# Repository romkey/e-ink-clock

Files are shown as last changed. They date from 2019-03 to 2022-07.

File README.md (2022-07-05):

# e-ink wifi clock



_This is a work in progress. I'm still testing and updating the hardware, and the software is incomplete. Build at your own risk._

Use a Waveshare epaper (e-ink) display as a digital wifi clock. The clock synchronizes its time with NTP and can show local weather using OpenWeatherMap.

The clock also supports an optional environmental sensor module, which allows it to report the temperature, humidity and air pressure in the space it's in.

It also supports an optional DS3231 I2C real time clock with battery backup module. This allows it to know the time immediately upon booting, even without NTP, and to keep time more accurately than just the ESP32 is capable of.

FInally, it also supports an optional ambient light sensor. This allows the clock to power down the e-ink module in the dark (when it is unreadable), which should extend the lifespan of the module.

# Hardware

Eagle schematics and board are in the `eagle` directory. 

_The hardware is still in testing; I cannot make any promises about its suitability for any use or its reliability._

Prices are obviously from the time I made this list. Links to parts are meant to show parts that have identical pinouts to the ones I used in the PC board layout. The specific items may become unavailable over time or the listings might even change to other parts with incompatible pinouts, so *please be careful to make sure you get parts with the correct pinouts* if you want to use the PC board - this is meant to be a guide to the parts and not a specific shopping list. 

| Part | AliExpress | Amazon | Notes |
|---|---:|---:|--|
|Waveshare 4.2" epaper module | [$28.79](https://www.aliexpress.com/item/400x300-4-2inch-E-Ink-display-module-No-backlight-Ultra-low-power-consumption-SPI-interface-Compatible/32826601765.html) | [$38.99](https://www.amazon.com/gp/product/B074NR1SW2) | |
|Wemos LOLIN32 ESP32 | [$5.50](https://www.aliexpress.com/item/ESP-32-ESP32-ESP-WROOM-32-for-WeMos-D1-LOLIN32-V1-0-02-WIFI-Bluetooth-Development/32887251214.html) | [$9.99 + $4.99](https://www.amazon.com/Beaster-LOLIN32-V1-0-0-Bluetooth-Development/dp/B07KFF1GJK) | |
|BME280 breakout | [$2.50](https://www.aliexpress.com/item/High-Accuracy-3In1-BME280-Digital-Sensor-Temperature-Humidity-Barometric-Pressure-Sensor-Module-GY-BME280-I2C-SPI/32817230797.html) | [$11.20](https://www.amazon.com/gp/product/B0775XFW69) | *optional*  lets you read the temperature, hunmidity and pressure where the clock is |
|DS3231 RTC breakout | [$1.04](https://www.aliexpress.com/item/DS3231-AT24C32-IIC-High-Precision-RTC-Module-Clock-Timer-Memory-Module/2037934408.html) | [$6.99](https://www.amazon.com/gp/product/B01IXXACD0) | *optional* keeps more accurate time, works without NTP or wifi |
|photoresistor | []() | []() | *optional* lets the clock power off display in the dark |
| |$37.83 | $72.16 |

Obviously AliExpress is an economical choice if you can wait a month or more for your parts to arrive. 

The printed circuit board uses breakout boards and is easy to assemble. The current version is at https://oshpark.com/shared_projects/apAIFWjg

# Software

The e-ink clock software is built using the Arduino SDK. It builds under [PlatformIO](https://platformio.org/) but with a little rearranging you could also build it with the Arduino IDE.

The application uses the [GxEPD](https://github.com/ZinggJM/GxEPD) library to drive the Waveshare display. GxEPD is a subclass of [Adafruit_GFX](https://github.com/adafruit/Adafruit-GFX-Library), so you can use its API to talk to the display. It also supports fast partial update on some Waveshare displays, which lets you write to the display much faster than a full screen write, without distracting flashing.

## Resources:

- turn an image file into a C language bitmap - [image2cpp](https://javl.github.io/image2cpp/)
- use `fontconvert` from Adafruit GFX Library to convert fonts to Adafruit GFX format

## Configuration

Copy `src/config.h-example` to `src/config.h` and set the constants in the file as you need them:
- `WIFI_SSID1`, `WIFI_PASSWORD1` - your primary WiFi SSID and password 
- `WIFI_SSID2`, `WIFI_PASSWORD2` - your backup WiFi SSID and password  - set to the same as primary if you don't have a backup
- `WIFI_SSID3`, `WIFI_PASSWORD3` - your bakup backup WiFi SSID and password  - set to the same as backup if you don't have a backup backup

## License

Permission to use this software is granted under the [MIT License](https://romkey.mit-license.org).

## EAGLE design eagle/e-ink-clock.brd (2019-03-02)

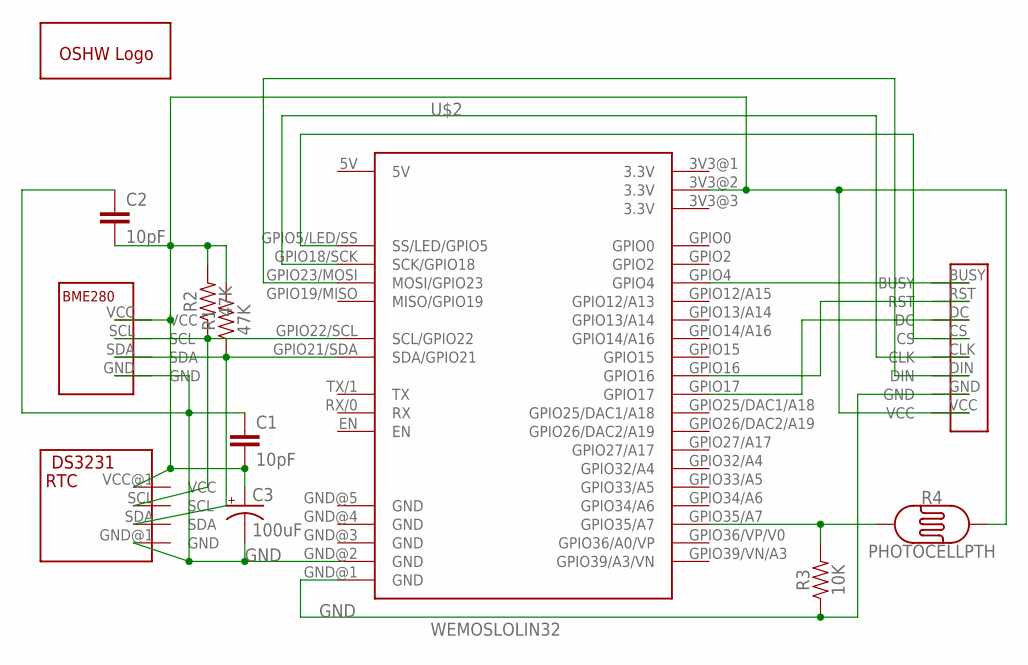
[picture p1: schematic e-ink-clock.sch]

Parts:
C1, C2: 10pF; CAP-PTH-SMALL2
C3: 100uF; CPOL-RADIAL-2.5MM-6.5MM
GOLD_ORB_SM1: OSHWLOGOLOGO16MM; OSHW_16MM
R1, R2: 47K; AXIAL-0.3
R3: 10K; AXIAL-0.3
R4: PHOTOCELLPTH; PHOTOCELL
U$1: WAVESHAREE-INK; WAVESHARE-EINK
U$2: WEMOSLOLIN32; LOLIN32VAR1
U$3: BME280BREAKOUTBME280; HDRV4W64P254_1X4_1016X508X838B
U$4: DS3231BREAKOUT

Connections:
3.3V: C1.2, C2.2, C3.1 (+), R1.P$2 (2), R2.P$2 (2), R4.2, U$1.VCC, U$2.3V3@2 (3.3V), U$2.3V3@3 (3.3V), U$3.VCC, U$4.VCC@1 (VCC)
5V: U$2.5V
GND: C1.1, C2.1, C3.2 (-), R3.P$1 (1), U$1.GND, U$2.GND@1 (GND), U$2.GND@2 (GND), U$3.GND, U$4.GND@1 (GND)
unnamed: U$1.CLK, U$2.GPIO18/SCK (SCK/GPIO18)
unnamed: U$1.CS, U$2.GPIO5/LED/SS (SS/LED/GPIO5)
unnamed: R2.P$1 (1), U$2.GPIO22/SCL (SCL/GPIO22), U$3.SCL, U$4.SCL
unnamed: R1.P$1 (1), U$2.GPIO21/SDA (SDA/GPIO21), U$3.SDA, U$4.SDA
unnamed: U$1.BUSY, U$2.GPIO4
unnamed: U$1.RST, U$2.GPIO16
unnamed: U$1.DC, U$2.GPIO17
unnamed: U$1.DIN, U$2.GPIO23/MOSI (MOSI/GPIO23)
unnamed: R3.P$2 (2), R4.1, U$2.GPIO35/A7

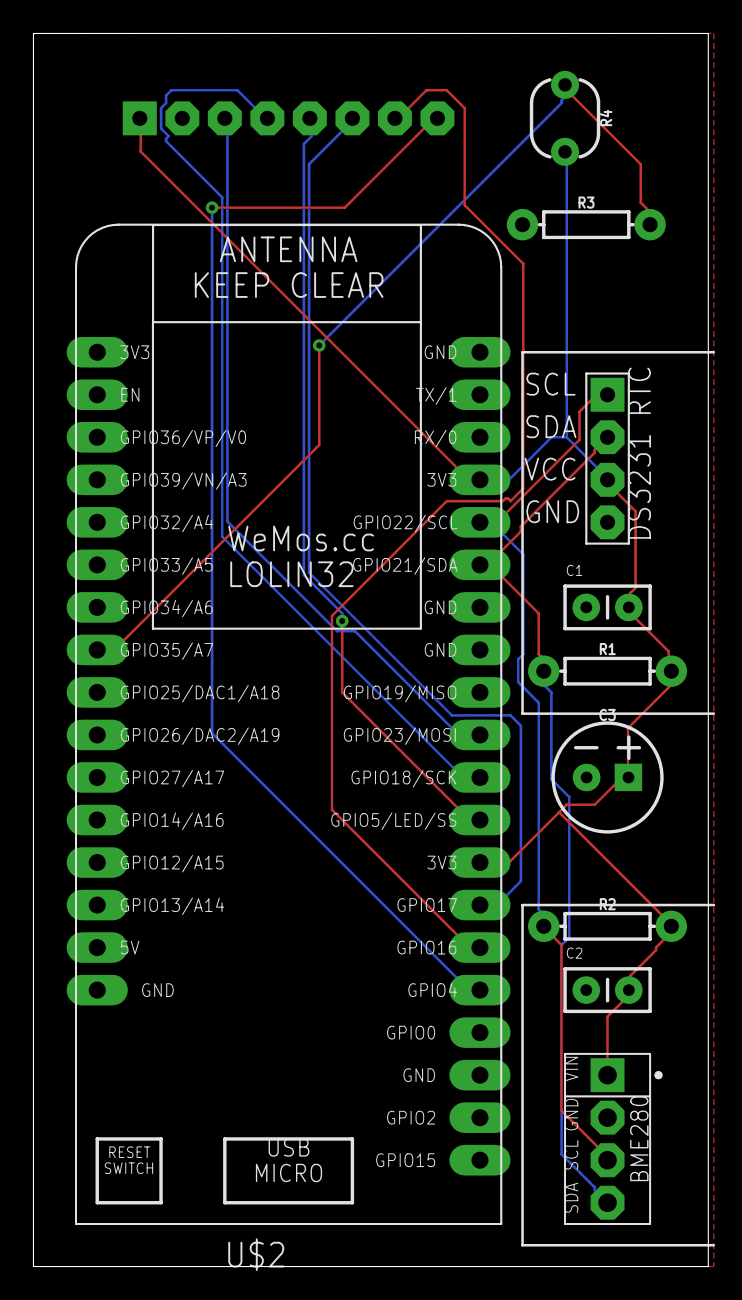
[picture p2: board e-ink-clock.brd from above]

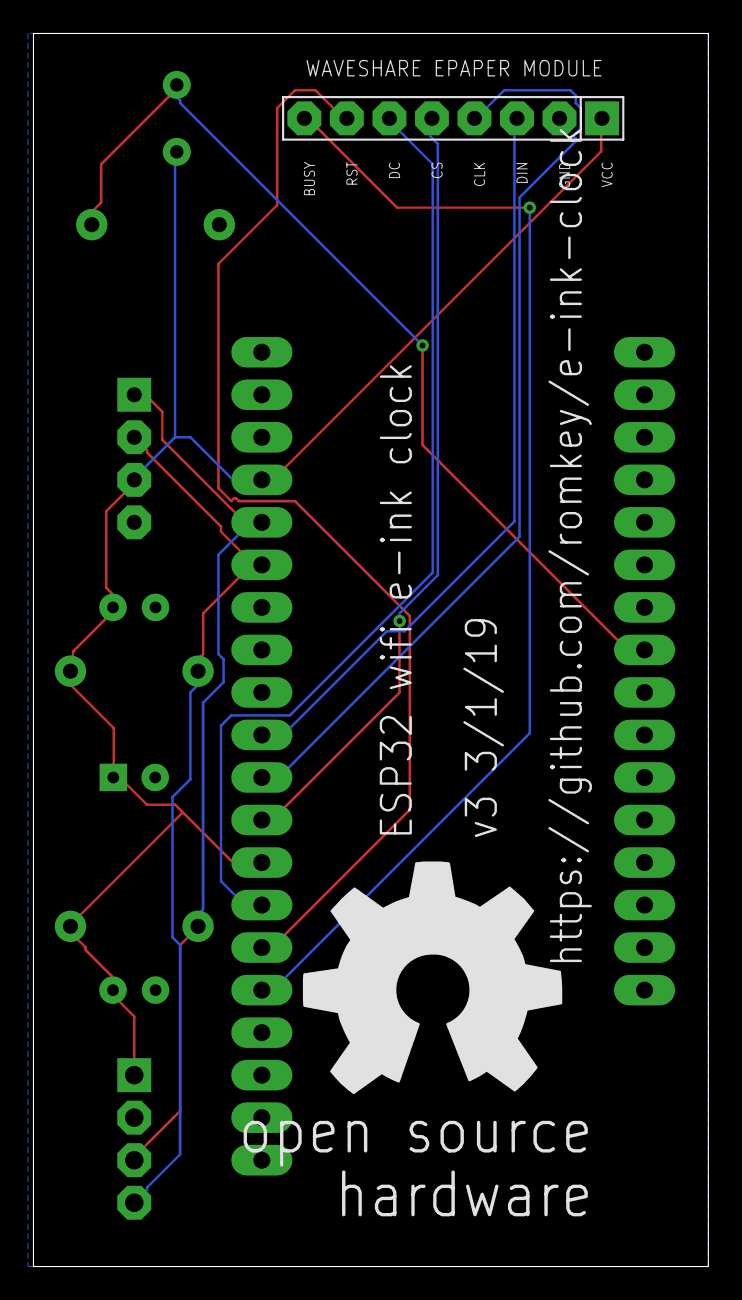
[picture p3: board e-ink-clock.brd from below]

Board: 2 copper layers, 40.3 x 73.7 mm, 12 parts (2 on the bottom side), 11 nets.

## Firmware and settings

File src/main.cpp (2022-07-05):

#include <Arduino.h>

#include <WiFi.h>
#include <WiFiMulti.h>
#include <ESPmDNS.h>
#include <ArduinoOTA.h>

#include "config.h"

#include "OpenWeatherMap.h"

OpenWeatherMap owm(OPEN_WEATHERMAP_API_KEY, OPEN_WEATHERMAP_CITY_CODE);

#include <PubSubClient.h>
static WiFiClient wifi_mqtt_client;
static PubSubClient mqtt_client(wifi_mqtt_client);

#include <Adafruit_Sensor.h>
#include <Adafruit_BME280.h>

#define SEALEVELPRESSURE_HPA (1013.25)
Adafruit_BME280 bme280;

#include "ui.h"

// BUSY -> 4, RST -> 16, DC -> 17, CS -> SS(5), CLK -> SCK(18), DIN -> MOSI(23), GND -> GND, 3.3V -> 3.3V

// GxIO_Class  io(SPI, CS, MOSI, RST, BL);
// GxEPD_Class display(io, rst, busy);
GxIO_Class     io(SPI, SS, 17, 16);
GxEPD_Class    display(io, 16, 4);

ClockUI clock_ui(&display);

#include "uptime.h"

Uptime uptime;

#define AMBIENT_LIGHT_PIN 35

#include <rom/rtc.h>

const char* reboot_reason(int code) {
  switch(code) {
    case 1 : return "POWERON_RESET";          /**<1, Vbat power on reset*/
    case 3 : return "SW_RESET";               /**<3, Software reset digital core*/
    case 4 : return "OWDT_RESET";             /**<4, Legacy watch dog reset digital core*/
    case 5 : return "DEEPSLEEP_RESET";        /**<5, Deep Sleep reset digital core*/
    case 6 : return "SDIO_RESET";             /**<6, Reset by SLC module, reset digital core*/
    case 7 : return "TG0WDT_SYS_RESET";       /**<7, Timer Group0 Watch dog reset digital core*/
    case 8 : return "TG1WDT_SYS_RESET";       /**<8, Timer Group1 Watch dog reset digital core*/
    case 9 : return "RTCWDT_SYS_RESET";       /**<9, RTC Watch dog Reset digital core*/
    case 10 : return "INTRUSION_RESET";       /**<10, Instrusion tested to reset CPU*/
    case 11 : return "TGWDT_CPU_RESET";       /**<11, Time Group reset CPU*/
    case 12 : return "SW_CPU_RESET";          /**<12, Software reset CPU*/
    case 13 : return "RTCWDT_CPU_RESET";      /**<13, RTC Watch dog Reset CPU*/
    case 14 : return "EXT_CPU_RESET";         /**<14, for APP CPU, reseted by PRO CPU*/
    case 15 : return "RTCWDT_BROWN_OUT_RESET";/**<15, Reset when the vdd voltage is not stable*/
    case 16 : return "RTCWDT_RTC_RESET";      /**<16, RTC Watch dog reset digital core and rtc module*/
    default : return "NO_MEAN";
  }
}

WiFiMulti wifiMulti;

unsigned long start_showing_clock = 0;

#ifdef BUILD_INFO

#define STRINGIZE_NX(A) #A
#define STRINGIZE(A) STRINGIZE_NX(A)

static char build_info[] = STRINGIZE(BUILD_INFO);
#else
static char build_info[] = "not set";
#endif

static char hostname[sizeof("eink-clock-%02x%02x%02x") + 1];

static RTC_DATA_ATTR int bootCount = 0;
static RTC_DATA_ATTR int wifi_failures = 0;

void command_callback(const char* topic, byte* payload, unsigned int length);

void setup() {
  byte mac_address[6];

  bootCount++;
  
  delay(500);

  randomSeed(analogRead(0));
  Serial.begin(115200);
  Serial.println("Hello world");

  WiFi.macAddress(mac_address);
  snprintf(hostname, sizeof(hostname), "eink-clock-%02x%02x%02x", (int)mac_address[3], (int)mac_address[4], (int)mac_address[5]);
  Serial.printf("Hostname is %s\n", hostname);

  WiFi.setHostname(hostname);

  Serial.println("Starting...");
  clock_ui.begin();
  delay(1000);
  Serial.println("eink setup done");

#if 0
  clock_ui.test();
  Serial.println("test done");
  delay(100000);
#endif

  Serial.println("[wifi]");

  wifiMulti.addAP(WIFI_SSID1, WIFI_PASSWORD1);
  wifiMulti.addAP(WIFI_SSID2, WIFI_PASSWORD2);
  wifiMulti.addAP(WIFI_SSID3, WIFI_PASSWORD3);
  wifiMulti.run();

  //  clock_ui.show_wifi_symbol();
  
  while(wifiMulti.run() != WL_CONNECTED) {
    Serial.print(".");
    delay(200);
  }

  Serial.print("Local IP ");
  Serial.println(WiFi.localIP());

  if(!MDNS.begin(hostname))
    Serial.println("Error setting up MDNS responder!");
  else
    Serial.println("[mDNS]");

  Serial.println("[NTP]");
  configTime(TZ_OFFSET, DST_OFFSET, "pool.ntp.org", "time.nist.gov");

  Serial.println("[OTA]");
  ArduinoOTA.setHostname(hostname);
  ArduinoOTA
    .onStart([]() {
      String type;
      if (ArduinoOTA.getCommand() == U_FLASH)
        type = "sketch";
      else // U_SPIFFS
        type = "filesystem";

      // NOTE: if updating SPIFFS this would be the place to unmount SPIFFS using SPIFFS.end()
      Serial.println("Start updating " + type);
    })
    .onEnd([]() {
      Serial.println("\nEnd");
    })
    .onProgress([](unsigned int progress, unsigned int total) {
      Serial.printf("Progress: %u%%\r", (progress / (total / 100)));
    })
    .onError([](ota_error_t error) {
	char buffer[10];
	snprintf(buffer, 10, "%u", error);

      Serial.printf("Error[%u]: ", error);
      if (error == OTA_AUTH_ERROR) Serial.println("Auth Failed");
      else if (error == OTA_BEGIN_ERROR) Serial.println("Begin Failed");
      else if (error == OTA_CONNECT_ERROR) Serial.println("Connect Failed");
      else if (error == OTA_RECEIVE_ERROR) Serial.println("Receive Failed");
      else if (error == OTA_END_ERROR) Serial.println("End Failed");
    });


  clock_ui.clear_wifi_symbol();

  clock_ui.show_network_info(WiFi.localIP(), HOSTNAME, WiFi.SSID().c_str());

  //  start_showing_clock = millis() + 30 * 1000;
  start_showing_clock = millis() + 1 * 1000;

#if 0
  display.update();
#endif

  ArduinoOTA.begin();

  mqtt_client.setServer(MQTT_HOST, MQTT_PORT);
  mqtt_client.connect(MQTT_UUID, MQTT_USER, MQTT_PASS);
  mqtt_client.setCallback(command_callback);
  mqtt_client.subscribe("/eink-clock/cmd");

  Serial.println("[homebus]");
  Serial.println("[mqtt]");

  if(!bme280.begin(0x76)) {
    Serial.println("bme280 fail");
  }
  Serial.println("[bme280]");

  Serial.println("[setup done]");
}

void update_time() {
  //   uint16_t cursor_y = time_box.y + 16;
  struct tm timeinfo;
  time_t now;

  now = time(NULL);
  localtime_r(&now, &timeinfo);

  clock_ui.show_time(&timeinfo);

  Serial.println(asctime(&timeinfo));
}

void owm_conditions() {
  static float last_outdoor_tempearture = 0;
  static float last_outdoor_humidity = 0;

  OpenWeatherMapConditions current = owm.current();

  clock_ui.show_outdoor(current.temp, current.humidity);
}

static float last_indoor_temperature = 0;
static float last_indoor_humidity = 0;

void update_indoor_conditions() {
  if(last_indoor_temperature && last_indoor_humidity)
    clock_ui.show_indoor(last_indoor_temperature, last_indoor_humidity);
}

#define CLOCK 0
#define REHAB 1
static int mode = CLOCK;

void command_callback(const char* topic, byte* payload, unsigned int length) {
  char payload_str[length+1];
  memcpy(payload_str, payload, length);
  payload_str[length] = '\0';

  Serial.printf("command: topic %s, payload %s\n", topic, payload_str);

  if(strcmp(payload_str, "restart") == 0)
    ESP.restart();

  if(strcmp(payload_str, "clock") == 0) {
    Serial.println("clock mode");
    mode = CLOCK;
  }

  if(strcmp(payload_str, "rehab") == 0) {
    Serial.println("rehab mode");
    mode = REHAB;
  }

  if(strcmp(payload_str, "ping") == 0)
    mqtt_client.publish("/eink-clock/cmd", "\"pong\"");
}

void loop_rehab() {
  static int submode = 0;
  static unsigned long next_rehab_update = 0;

  if(next_rehab_update > millis())
    return;

  switch(submode) {
  case 0:
    display.fillScreen(GxEPD_WHITE);
    display.update();
    submode++;
    break;
  case 1:
    display.fillScreen(GxEPD_BLACK);
    display.update();
    submode++;
    break;
  case 2:
    display.fillScreen(GxEPD_WHITE);
    display.update();
    submode++;
    break;
  case 3:
    for(int x = 0; x < 400;  x += 10)
      for(int y = 0; y < 300; y += 10) {
	for(int i = 0; i < 5; i++)
	  for(int j = 0; j < 5 ; j++)
	    display.drawPixel(x+i, y+j, GxEPD_WHITE);

	for(int i = 0; i < 5; i++)
	  for(int j = 0; j < 5 ; j++)
	    display.drawPixel(x+i+5, y+j+5, GxEPD_BLACK);
      }
    display.update();
    submode++;
    break;
  case 4:
    for(int x = 0; x < 400;  x += 10)
      for(int y = 0; y < 300; y += 10) {
	for(int i = 0; i < 5; i++)
	  for(int j = 0; j < 5 ; j++)
	    display.drawPixel(x+i, y+j, GxEPD_BLACK);

	for(int i = 0; i < 5; i++)
	  for(int j = 0; j < 5 ; j++)
	    display.drawPixel(x+i+5, y+j+5, GxEPD_WHITE);
      }
    display.update();
    submode++;
    break;
  case 5:
    submode = 0;
    return;
  };

  next_rehab_update += 3*60*1000;
}

void loop_clock() {
  static unsigned long next_weather_update = 0;
  static uint8_t draw_clock_ui = 1;

  if(draw_clock_ui) {
    draw_clock_ui = 0;
    clock_ui.setup_time();
  }

  static tm last_timeinfo = {
    .tm_sec = -1,
    .tm_min = -1
  };

  struct tm timeinfo;
  time_t now;

  now = time(NULL);
  localtime_r(&now, &timeinfo);

#ifdef CHECK_AMBIENT_LIGHT
  if(last_timeinfo.tm_sec != timeinfo.tm_sec && ambient_light > 0) {
#else
  if(last_timeinfo.tm_sec != timeinfo.tm_sec) {
#endif
    update_time();
    last_timeinfo = timeinfo;
  }

#ifdef CHECK_AMBIENT_LIGHT
  if(millis() > next_weather_update && ambient_light > 0) {
#else
  if(millis() > next_weather_update) {
#endif
    next_weather_update += 1000 * 60;

    owm.update_current();
    owm_conditions();
  }
}

void loop() {
  static unsigned long last_mqtt_check = 0;

  unsigned ambient_light = analogRead(AMBIENT_LIGHT_PIN);

  mqtt_client.loop();

  if(millis() > last_mqtt_check + 5000) {
    if(!mqtt_client.connected()) {
      mqtt_client.connect(MQTT_UUID, MQTT_USER, MQTT_PASS);
      mqtt_client.subscribe("/eink-clock/cmd");
      Serial.println("mqtt reconnect");
    }

    last_mqtt_check = millis();
  }

  ArduinoOTA.handle();

  if(mode == REHAB)
    loop_rehab();

  if(millis() < start_showing_clock)
    return;

  if(mode ==  CLOCK)
    loop_clock();

  static unsigned long next_bme280_update = 1000*10;
  if(millis() > next_bme280_update) {
    bool redraw = false;

    next_bme280_update = millis() + 1000*10;

    if(last_indoor_temperature != bme280.readTemperature()) {
      last_indoor_temperature = bme280.readTemperature();
      redraw = true;
    }

    if(last_indoor_humidity != bme280.readHumidity()) {
      last_indoor_humidity = bme280.readHumidity();
      redraw = true;
    }
    
#ifdef CHECK_AMBIENT_LIGHT
    if(mode == CLOCK && redraw && ambient_light > 0)
#else
    if(mode == CLOCK && redraw)
#endif
      update_indoor_conditions();

    Serial.print("BME280 Temperature = ");
    Serial.print(last_indoor_temperature);
    Serial.println(" *C");

    Serial.print("Pressure = ");
    Serial.print(bme280.readPressure());
    Serial.println(" hPa");

    Serial.print("Approx. Altitude = ");
    Serial.print(bme280.readAltitude(SEALEVELPRESSURE_HPA));
    Serial.println(" m");

    Serial.print("Humidity = ");
    Serial.print(last_indoor_humidity);
    Serial.println(" %");

    Serial.printf("Ambient light %u\n", ambient_light);

    Serial.println();

    static unsigned long last_mqtt_update = 0;
    if(millis() - last_mqtt_update > (60 * 1000))  {
      last_mqtt_update = millis();
      char buffer[500];
      IPAddress local = WiFi.localIP();

      static bool first = true;
      if(first) {
	first = false;
	snprintf(buffer, 500, "{ \"id\": \"%s\", \"message\": \"booted\", \"system\": { \"name\": \"%s\", \"build\": \"%s\", \"ip\": \"%d.%d.%d.%d\", \"rssi\": %d } }",
		 MQTT_UUID,
		 hostname, build_info, local[0], local[1], local[2], local[3], WiFi.RSSI());
	mqtt_client.publish("/eink-clock/log", buffer, true);
      }

      snprintf(buffer, 500, "{ \"id\": \"%s\", \"system\": { \"name\": \"%s\", \"build\": \"%s\", \"freeheap\": %d, \"uptime\": %lu, \"ip\": \"%d.%d.%d.%d\", \"rssi\": %d, \"reboots\": %d, \"wifi_failures\": %d  }, \"environment\": { \"temperature\": %0.1f, \"humidity\": %0.1f, \"pressure\": %0.1f },  \"light\": %u }",
	       MQTT_UUID,
	       hostname, build_info, ESP.getFreeHeap(), uptime.uptime()/1000,  local[0], local[1], local[2], local[3], WiFi.RSSI(), bootCount, wifi_failures,
	       last_indoor_temperature, bme280.readHumidity(), bme280.readPressure()/100.0,
	       ambient_light);

      Serial.println(buffer);
      mqtt_client.publish("/eink-clock", buffer, true);
    }
  }
}

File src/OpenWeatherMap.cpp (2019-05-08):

#ifndef ESP32
#include <ESP8266WiFi.h>
#include <ESP8266HTTPClient.h>
#endif

#ifdef ESP32
#include <WiFi.h>
#include <HTTPClient.h>
#endif

#include <JsonStreamingParser.h>

#include "OpenWeatherMap.h"
#include "OpenWeatherMapCurrentListener.h"

#ifdef OPENWEATHERMAP_HTTPS
#define OPENWEATHERMAP_PROTOCOL "https"
#else
#define OPENWEATHERMAP_PROTOCOL "http"
#endif

#define WEATHER_URL        OPENWEATHERMAP_PROTOCOL "://api.openweathermap.org/data/2.5/weather"
#define FORECAST_5DAY_URL  OPENWEATHERMAP_PROTOCOL "://api.openweathermap.org/data/2.5/forecast"

#define PORTLAND_CITY_ID    5746545

#ifdef ESP32
const char* _openweathermap_root_certificate = \
"-----BEGIN CERTIFICATE-----\n" \
"MIIE0DCCA7igAwIBAgIBBzANBgkqhkiG9w0BAQsFADCBgzELMAkGA1UEBhMCVVMx" \
"EDAOBgNVBAgTB0FyaXpvbmExEzARBgNVBAcTClNjb3R0c2RhbGUxGjAYBgNVBAoT" \
"EUdvRGFkZHkuY29tLCBJbmMuMTEwLwYDVQQDEyhHbyBEYWRkeSBSb290IENlcnRp" \
"ZmljYXRlIEF1dGhvcml0eSAtIEcyMB4XDTExMDUwMzA3MDAwMFoXDTMxMDUwMzA3" \
"MDAwMFowgbQxCzAJBgNVBAYTAlVTMRAwDgYDVQQIEwdBcml6b25hMRMwEQYDVQQH" \
"EwpTY290dHNkYWxlMRowGAYDVQQKExFHb0RhZGR5LmNvbSwgSW5jLjEtMCsGA1UE" \
"CxMkaHR0cDovL2NlcnRzLmdvZGFkZHkuY29tL3JlcG9zaXRvcnkvMTMwMQYDVQQD" \
"EypHbyBEYWRkeSBTZWN1cmUgQ2VydGlmaWNhdGUgQXV0aG9yaXR5IC0gRzIwggEi" \
"MA0GCSqGSIb3DQEBAQUAA4IBDwAwggEKAoIBAQC54MsQ1K92vdSTYuswZLiBCGzD" \
"BNliF44v/z5lz4/OYuY8UhzaFkVLVat4a2ODYpDOD2lsmcgaFItMzEUz6ojcnqOv" \
"K/6AYZ15V8TPLvQ/MDxdR/yaFrzDN5ZBUY4RS1T4KL7QjL7wMDge87Am+GZHY23e" \
"cSZHjzhHU9FGHbTj3ADqRay9vHHZqm8A29vNMDp5T19MR/gd71vCxJ1gO7GyQ5HY" \
"pDNO6rPWJ0+tJYqlxvTV0KaudAVkV4i1RFXULSo6Pvi4vekyCgKUZMQWOlDxSq7n" \
"eTOvDCAHf+jfBDnCaQJsY1L6d8EbyHSHyLmTGFBUNUtpTrw700kuH9zB0lL7AgMB" \
"AAGjggEaMIIBFjAPBgNVHRMBAf8EBTADAQH/MA4GA1UdDwEB/wQEAwIBBjAdBgNV" \
"HQ4EFgQUQMK9J47MNIMwojPX+2yz8LQsgM4wHwYDVR0jBBgwFoAUOpqFBxBnKLbv" \
"9r0FQW4gwZTaD94wNAYIKwYBBQUHAQEEKDAmMCQGCCsGAQUFBzABhhhodHRwOi8v" \
"b2NzcC5nb2RhZGR5LmNvbS8wNQYDVR0fBC4wLDAqoCigJoYkaHR0cDovL2NybC5n" \
"b2RhZGR5LmNvbS9nZHJvb3QtZzIuY3JsMEYGA1UdIAQ/MD0wOwYEVR0gADAzMDEG" \
"CCsGAQUFBwIBFiVodHRwczovL2NlcnRzLmdvZGFkZHkuY29tL3JlcG9zaXRvcnkv" \
"MA0GCSqGSIb3DQEBCwUAA4IBAQAIfmyTEMg4uJapkEv/oV9PBO9sPpyIBslQj6Zz" \
"91cxG7685C/b+LrTW+C05+Z5Yg4MotdqY3MxtfWoSKQ7CC2iXZDXtHwlTxFWMMS2" \
"RJ17LJ3lXubvDGGqv+QqG+6EnriDfcFDzkSnE3ANkR/0yBOtg2DZ2HKocyQetawi" \
"DsoXiWJYRBuriSUBAA/NxBti21G00w9RKpv0vHP8ds42pM3Z2Czqrpv1KrKQ0U11" \
"GIo/ikGQI31bS/6kA1ibRrLDYGCD+H1QQc7CoZDDu+8CL9IVVO5EFdkKrqeKM+2x" \
"LXY2JtwE65/3YR8V3Idv7kaWKK2hJn0KCacuBKONvPi8BDAB" \
"-----END CERTIFICATE-----\n";
#endif

OpenWeatherMap::OpenWeatherMap(const char* api_key, const char* zip) : OpenWeatherMap::OpenWeatherMap(api_key) {
  _zip_code = zip;
}

OpenWeatherMap::OpenWeatherMap(const char* api_key, int id) : OpenWeatherMap::OpenWeatherMap(api_key) {
  _city_id = id;
}

OpenWeatherMap::OpenWeatherMap(const char* api_key) {
  strncpy(_api_key, api_key, OPENWEATHERMAP_API_KEY_LENGTH);
  _openweathermap_fingerprint = _OPENWEATHERMAP_FINGERPRINT;
}

int OpenWeatherMap::update_current() {
  HTTPClient http;
  char url[250];

  snprintf(url, 250, "%s?id=%d&APPID=%s", WEATHER_URL, _city_id, _api_key);
  //  snprintf(url, 250, "%s?id=%d&APPID=%s", FORECAST_5DAY_URL, _city_id, _api_key);
  Serial.println(url);

#ifdef ESP32
  // certificate: openssl s_client -showcerts -connect maker.ifttt.com:443 < /dev/null
  //  http.begin(url, _openweathermap_root_certificate);
  http.begin(url);
#else
  // fingerprint: openssl s_client -connect maker.ifttt.com:443  < /dev/null 2>/dev/null | openssl x509 -fingerprint -noout | cut -d'=' -f2
  //  http.begin(url, _openweathermap_fingerprint);
  http.begin(url);
#endif

  Serial.println("1");

  int httpCode = http.GET();
  Serial.println("1.0");

  if(httpCode > 0) {
    Serial.println("1.1");

    Serial.printf("[HTTP] GET... code: %d\n", httpCode);

    if(httpCode != HTTP_CODE_OK) {
      Serial.println("1.2");
      http.end();
      Serial.printf("[HTTP] GET... failed, error: %s\n", http.errorToString(httpCode).c_str());
      return -1;
    }
  } else {
    Serial.println(httpCode);
    Serial.println("1.3");
    http.end();
    Serial.println("1.4");
    return -1;
  }

  Serial.println("2");

  Serial.println("JSON!");
  String json_str = http.getString();
  Serial.println(json_str);
 
  JsonStreamingParser parser;
  OpenWeatherMapCurrentListener listener;

  parser.setListener(&listener);

  for (int i = 0; i < json_str.length(); i++) {
    parser.parse(json_str[i]);
  }

  Serial.println(C_TO_F(listener._conditions.temp));

  _current_conditions = listener._conditions;

  return 0;
}

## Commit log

2019-03-02 read temperature and hunidity from a BME280 and show on display
2019-03-02 doc update
    Eagle files
    [e-ink-clock.brd, e-ink-clock.sch]
2019-05-08 a little bit of OpenWeatherMap API support
    post data to MQTT server
    font work
    track uptime

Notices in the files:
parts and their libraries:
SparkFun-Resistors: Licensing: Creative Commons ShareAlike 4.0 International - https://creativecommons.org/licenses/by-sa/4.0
